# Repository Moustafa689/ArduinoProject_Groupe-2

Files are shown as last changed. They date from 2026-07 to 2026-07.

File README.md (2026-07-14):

# Automated Greenhouse System — Groupe 2 🌿
**Lebanese University — Faculty of Engineering III** **Course:** Sensors & Instrumentation  
**Instructor:** Dr. Mohamad Aoude  

## 📂 GitHub Repository Structure

In accordance with the project guidelines, this repository is organized as follows:

* 📁 [**`README.md`**](./README.md) — This main documentation page.
* 📁 [**`/Docs`**](./Docs) — Project schematics, wiring diagrams, and technical documentation.
* 📁 [**`/code`**](./code) — The implementation source code for the Arduino.
* 📁 [**`/video`**](./video) — Project demonstration video references.
* 📁 [**`/Reports`**](./Reports) — The Main Project Report alongside all individual group member reports.

---
## 📋 Project Subsystems & Video Outline

Our integrated greenhouse automation system is broken down into five key subsystems: 

1. **System Overview** – Overall architecture, hardware layout, and sensor placement.
2. **Security & Alarm System** – Intrusion detection utilizing a motion sensor and active buzzer.
3. **Climate Control** – Ambient temperature and humidity regulation via a DHT11 sensor and fan.
4. **Automated Irrigation** – Soil moisture analysis controlling a self-triggering water pump.
5. **Weather & Light Response** – Light (LDR) and rain detection driving a servo-actuated roof.

---

## 📺 Project Demonstration Video

Click the video player thumbnail below to watch our complete system run-through and see all the sensors and actuators in action:

Watch the Video (https://youtu.be/gns5-Lyf4sU)

*(The demonstration details can also be found in the [**`/video`**](./video) directory).*

---

## 💻 Source Code & Libraries

The fully commented and modular Arduino codebase is stored in the code directory:

* 📄 [**`/code/Project_code.ino`**](./code/Project_code.ino) — Click here to view the main logic, pin mappings, and loop controls.

### 📦 Required Arduino Libraries
To compile the code successfully, make sure to install the following libraries included in the Arduino libraries manager:

1. **IRremote Library** (v4.0.0 or later) — *Handles IR receiver signals and protocol decoding.*
   - **Author:** Armin Joachimsmeyer
   - **Source URL:** [https://github.com/Arduino-IRremote/Arduino-IRremote](https://github.com/Arduino-IRremote/Arduino-IRremote)
   - **License:** MIT License
2. **IskakINO LiquidCrystal I2C Library** — *Drives our 16x2 character display over the I2C protocol.*
   - **Author:** IskakINO
   - **Source URL:** [https://github.com/IskakINO/IskakINO_LiquidCrystal_I2C](https://github.com/IskakINO/IskakINO_LiquidCrystal_I2C)
   - **License:** GNU General Public License v3.0 (GPL-3.0)
3. **DHT Sensor Library** by Adafruit (v1.4.6 or later) — *Communicates with the DHT11 temperature & humidity sensor.*
   - **Author:** Adafruit
   - **Source URL:** [https://github.com/adafruit/DHT-sensor-library](https://github.com/adafruit/DHT-sensor-library)
   - **License:** MIT License
4. **Adafruit Unified Sensor Library** — *A mandatory hardware abstraction dependency required by the DHT library.*
   - **Author:** Adafruit
   - **Source URL:** [https://github.com/adafruit/Adafruit_Sensor](https://github.com/adafruit/Adafruit_Sensor)
   - **License:** Apache License 2.0

*To install these in the Arduino IDE, go to **Sketch > Include Library > Add .ZIP Library...** and select the files from the `/code/libraries` directory.*

---

## 👥 Project Reports & Technical Documentation

All project documentation is compiled and stored inside the [**`/Reports`**](./Reports) folder. 

### 📑 Main Project Report
* [📘 **Download Main Project Report (PDF)**](./Reports/Development_and_Testing_of_an_Automated_Smart_Greenhouse_System_with_Integrated_Environmental_and_Security_Frameworks.pdf) — *The comprehensive, complete group technical report outlining the entire design, circuitry, budget, and results.*

### 📄 Individual Reports
Each team member took ownership of a specific module and compiled an individual technical analysis:

| Team Member | Subsystem Responsibility | Individual Report Link |
| :--- | :--- | :--- |
| **Razane Najem** | Security Subsystem & Alarm | [📄 View Report](./Reports/Individual_Technical_Report_Design_Power_Management_Circuit_Schematics_Control_Firmware_for_the_Embedded_Security_and_Alarm_System.pdf) |
| **Fatima Jaafar** | Climate Control (DHT11 & Fan) | [📄 View Report](./Reports/Individual_Technical_Report_Microclimate_Ventilation_and_Automatic_Temperature_Control_Power_Supply_Electrical_Schematics_and_Firmware_Code.pdf) |
| **Moustafa Alawieh** | Automated Irrigation (Soil & Pump) | [📄 View Report](./Reports/Individual_Technical_Report_Closed-Loop_Soil_Moisture_Sensing_and_Irrigation_Pump_Control_Power_Supply_Electrical_Schematics_and_Firmware_Code.pdf) |
| **Mohammad injibar** | Weather & Light (LDR/Rain/Servo) | [📄 View Report](./Reports/Individual_Technical_Report_Light-Sensing_Weather_Protection_and_Servo-Driven_Roof_Actuation_Power_Supply_Electrical_Schematics_and_Firmware_Code.pdf) |

---

## 🛠️ Hardware Schematics

* The complete wiring diagram and schematic can be found in the docs directory:  
  📄 [**`/Docs/Greenhouse_System_Schematic_And_Wiring.fzz`**](./Docs/Greenhouse_System_Schematic_And_Wiring.fzz) (Open with Fritzing).

---

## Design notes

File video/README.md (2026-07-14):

# 📹 Project Demonstration Video

Because the high-definition project demonstration video exceeds GitHub's file size limits, the full video is hosted on YouTube.

### 🔗 Watch the Demo Video:
* **Direct Link:** [https://youtu.be/gns5-Lyf4sU](https://youtu.be/gns5-Lyf4sU)

---

### 📺 Video Player Preview
Click the preview thumbnail below to play the video:

Watch the Video (https://youtu.be/gns5-Lyf4sU)

---

### 📋 Video Chapters & Subsystems Shown:
* **0:00** - Subsystem 1: System Overview & Setup
* **3:10** - Subsystem 2: Security Subsystem (PIR Sensor & Buzzer Alarm)
* **5:00** - Subsystem 3: Climate Control (DHT11 Temperature/Humidity & Fan) 
* **7:15** - Subsystem 4: Automated Irrigation (Soil Moisture Sensor & Water Pump)
* **8:46** - Subsystem 5: Weather & Light Response (LDR, Rain Sensor & Servo)

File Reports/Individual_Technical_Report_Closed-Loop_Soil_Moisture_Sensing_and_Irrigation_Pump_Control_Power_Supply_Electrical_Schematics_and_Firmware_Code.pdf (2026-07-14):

# الجامعة اللبنانية University Lebanese

Faculity Of Engineering - III | كلية الهندسة – الفرع 3

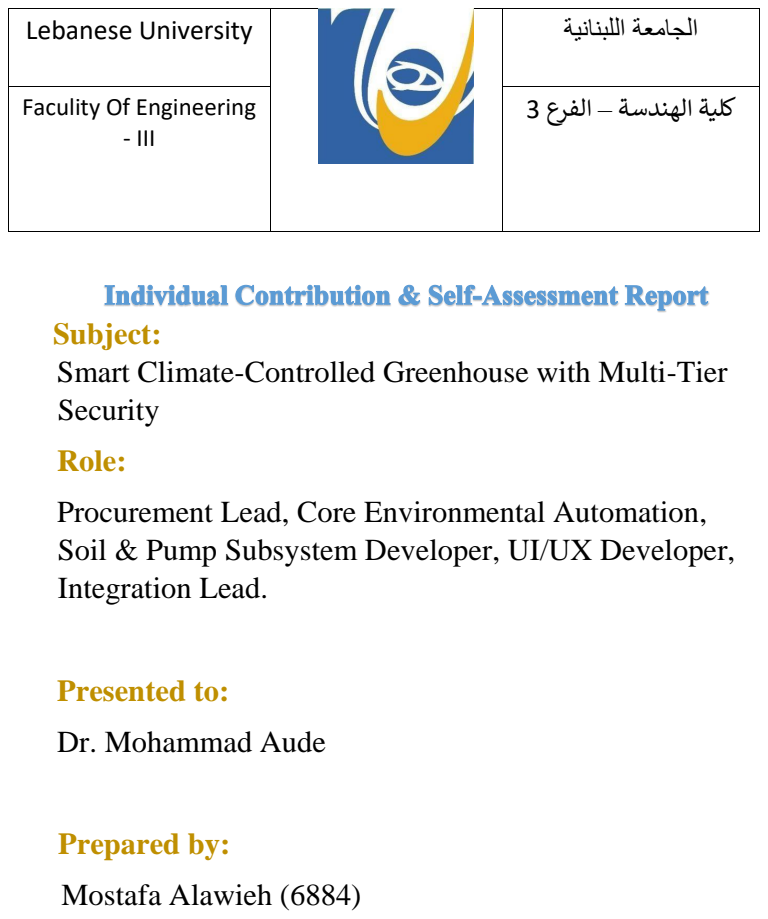
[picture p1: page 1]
Prepared by:; Mostafa Alawieh (6884)

Subject:
Smart Climate-Controlled Greenhouse with Multi-Tier
Security

Role:
Procurement Lead, Core Environmental Automation,
Soil & Pump Subsystem Developer, UI/UX Developer,
Integration Lead.

Presented to:
Dr. Mohammad Aude

# Contribution Summary

### 1. Introduction & Project Scope

In the development of our Smart Climate-Controlled Greenhouse and Security System, I acted as both the Logistics Lead and the Primary Systems & UI Integrator. My responsibilities spanned the entire lifecycle of the project—beginning with raw component sourcing, advancing through the design and firmware development of the core environmental feedback loops, and concluding with hardware-software integration, system troubleshooting, schematic verification, and final quality assurance (QA) validation.

By managing these crucial crossover phases, I bridged the gap between individual team modules to ensure a unified, robust system architecture.

### 2. Component Procurement & Hardware Diagnostics

During the initiation phase, Me and Mohamad took ownership of translating our conceptual block diagrams into a physical Bill of Materials (BOM). This required evaluating component datasheets to ensure electrical compatibility across our 5V and 3.3V logic levels.

- Microcontroller Selection: I procured an Arduino Mega 2560 instead of a standard Uno to provide sufficient SRAM and hardware timers to handle the concurrent execution of the IR Receiver, Servo library, DHT11, and ultrasonic pulse triggers.
- Actuator & Sensor Verification: I sourced and individually bench-tested all primary components— including the submersible water pump, liquid level sensor, capacitive soil moisture sensor, and standard dual-channel electromagnetic relay modules—to verify their current draw requirements and operational thresholds before system-wide integration.

### 3. Subsystem Engineering & Firmware Architecture

I designed, wired, and programmed three foundational subsystems that govern the climate control and visual feedback loops of the greenhouse:

- Closed-Loop Automatic Irrigation: I engineered the automated soil hydration loop. I implemented a clean, three-pin hardware interface connecting the soil moisture sensor directly to VCC, GND, and analog input pin A1. I wrote data-mapping algorithms that convert the sensor's raw analog voltage readings (0 to 1023 ADC steps) into a stable percentage scale (0% to 100%). To execute the physical watering safely, I isolated the high-current DC water pump using a standard 5V active-LOW electromagnetic relay on digital pin 5, safeguarding the microcontroller from back-EMF inductive voltage spikes generated by the pump motor.
- Liquid Reservoir Analytics: To protect the water pump from running dry and incurring permanent mechanical damage, I integrated an analog liquid level sensor. Utilizing a direct three-pin connection to VCC, GND, and analog pin A8, the sensor outputs a direct voltage proportional to liquid contact. I developed a software thresholding matrix that classifies these fluctuating voltages into four discrete reservoir states (DRY, LOW, MED, and HIGH) displayed dynamically to the user.

- I2C Display Hub & State-Machine UI: I integrated the 16x2 LCD UI. By implementing the I2C communication protocol (SDA and SCL pins), I reduced the display's physical pin requirement from 6 digital lines down to 2, preserving vital I/O pins on the Arduino. I programmed a non-blocking UI state machine using millis() timers that rotates through four distinct telemetry pages every 5 seconds, ensuring the screen refreshes continuously without stalling the time-sensitive security and IR remote polling routines.

### 4. System Integration, Testing, & Video Demonstration

As the integration lead, I consolidated our team's individual codebases (including the IR passcode system, automatic ventilation, and adaptive roof servo) into a single, cohesive sketch. During this phase, I resolved critical system-level issues, including ultrasonic sensor echo-flooding and voltage sags, by implementing non-blocking interval timers and a star-grounding architecture.

Crucially, I took full ownership of the final phase of the project, which involved planning, staging, filming, and presenting the entire integrated system operation in a detailed demonstration video. I systematically recorded each functional loop in real-time, demonstrating exactly how the sensors interact with the actuators (e.g., simulating soil dryness to trigger the pump, showing water level state updates, and triggering security breaches). By scripting and producing this in-depth video walkthrough, I provided comprehensive, step-bystep visual proof that our physical assembly and software logic operate flawlessly under simulated realworld conditions.

# Evidence of Work Performed

### 1. Subsystem A: CAD Schematic Design & Electrical Architecture

To transition our project from a conceptual design to a physical working prototype, I engineered and mapped the complete electrical routing using CAD software. The schematic details the exact pin configurations, voltage rails, and signal paths required to run the automated subsystems without signal degradation or component failure.

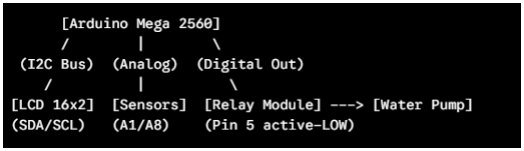
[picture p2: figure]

A. The I2C Display Interface Wiring

Standard parallel wiring for a 16×2 Character LCD typically requires a minimum of 6 digital I/O pins (Register Select, Enable, and 4 Data lines), which would severely limit the expansion capabilities of our Arduino board. To optimize pin utilization, I implemented an I2C serial-to-parallel interface daughterboard built onto the back of the LCD.

- This configuration allowed me to bus the display interface using only two physical communication wires:
- SDA (Serial Data Line): Wired directly to the hardware SDA pin (Pin 20) on the Arduino Mega.
- SCL (Serial Clock Line): Wired directly to the hardware SCL pin (Pin 21) on the Arduino Mega.
- The display module is powered directly from the filtered 5V and GND logic rails. By utilizing hardware I2C, I preserved digital pins for the time-critical interrupts needed by the ultrasonic sensor and IR receiver.
B. Direct Analog Sensor Signal Routing

The capacitive soil moisture sensor and the liquid level sensor are active breakout boards that perform onboard signal conditioning. They require direct, analog-to-digital measurement without external voltage dividers:

- Soil Moisture Sensor Interface: Connected directly to VCC(5V), GND, and the analog output signal routed to Analog Pin A1.
- Water Level Sensor Interface: Connected directly to VCC (5V), GND, and the analog signal routed to Analog Pin A8.
- Because these sensor boards regulate and output a direct, low-impedance analog voltage between 0V and 5V, they are immune to typical signal attenuation and do not require external pull-up or pull-down resistor networks, allowing for a clean, direct routing path to the Arduino Mega’s onboard 10-bit Analog-to-Digital Converter (ADC).
C. Standard 5V Electromagnetic Relay Circuit

To control the 12V high-current submersible water pump, I integrated a standard single-channel electromagnetic relay module on Digital Pin 5.

- Because the Arduino Mega’s I/O pins can safely source a maximum of only 40mA, they cannot directly drive the power-hungry electromagnetic coil of a mechanical relay (which typically requires 70mA to 100mA).
- The relay module contains an onboard NPN transistor driver circuit. The Arduino Pin 5 provides a tiny base current to switch this transistor, which in turn switches the larger coil current from the 5V supply rail.
- To safeguard the microcontroller from inductive flyback voltage spikes—which occur when the magnetic field of the relay coil collapses—the module includes an anti-parallel flyback diode across the coil terminals.

### 2. Subsystem B: Firmware Development & Signal Processing Algorithms

The software architecture governing my assigned subsystems was designed to optimize processing efficiency, minimize CPU overhead, and ensure real-time responsiveness. This was achieved by writing modular, non-blocking C++ code within the Arduino framework. Below is a rigorous technical analysis of the algorithms, mathematical models, and operational logic developed for the soil moisture monitoring, water level detection, and LCD user interface modules.

A. Non-Blocking Cooperative Multitasking Architecture

To prevent the microcontroller from stalling—which would disable the high-priority IR receiver and ultrasonic security systems—all of my code blocks strictly avoid the standard delay() function. Instead, I established a cooperative multitasking architecture utilizing the system’s hardware timer via the millis() function.

Each of my subsystems is assigned an independent software timer variable tracking elapsed execution cycles. For example:

By comparing the current CPU uptime (currentTime) against the last recorded run instance (pumpTimer), the microcontroller executes my tasks at exact 2-second (or 5-second) intervals. For the remaining time, the processor bypasses these blocks completely, maintaining a loop execution speed of several thousand cycles per second to process immediate inputs like the IR remote or security triggers.

B. Mathematical Calibration & Processing of the Soil Moisture Sensor

The capacitive soil moisture sensor outputs an analog voltage directly proportional to the dielectric permittivity of the surrounding soil matrix. This voltage is read by the Arduino's 10 -bit successive-approximation Analogto-Digital Converter (ADC) on Analog Pin A1, resulting in an integer value between 0 and 1023.

To convert this raw step integer into a physical, human-readable volumetric water content percentage (VWC%), I established a linear calibration model.

1. Air Calibration (Fully Dry Point): The sensor was suspended in open air to read the absolute
maximum dry limit, yielding an ADC value of 1023$(Vin =5.0V).
2. Saturated Calibration (Fully Wet Point): The sensor was submerged in water-saturated soil to read the absolute wet limit, yielding an ADC value of 250$(Vin =1.22V).

Using these empirical boundary conditions, I formulated the conversion using linear interpolation:

This mathematical relationship is executed in the firmware using the integer-based map() function. To ensure that extreme chemical concentrations or physical anomalies do not force the output beyond physical reality, the output is bound using the mathematical constrain() function:

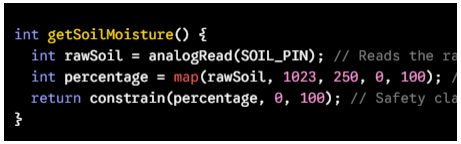
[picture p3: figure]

This calibrated percentage is fed directly to the hysteretic pump controller. If the moisture drops to 35% or lower, Pin 5 is written LOW to energize the pump relay. Because the loop polls every 2 seconds, it acts as a low-pass filter, preventing high-frequency noise from cycling the relay contacts too quickly.

C. Multi-Step Threshold Classification of the Water Reservoir Level

The liquid depth sensor utilizes a series of exposed, parallel conductive traces that act as a variable resistor. When water contacts the sensor, it completes a circuit path, altering the voltage on Analog Pin A8.

Unlike a continuous fluid-flow sensor, a simple depth sensor's raw voltage is highly non-linear and susceptible to surface ripple noise. To produce stable, reliable UI feedback, I designed a cascading threshold comparator algorithm that classifies the continuous analog voltage range into four discrete, logical states:

- Hysteresis Modeling: By separating the states by large analog steps (e.g., 50 -> 300 ->600), the system is immune to "display flicker" caused by water sloshing inside the reservoir.
- State Mapping: The integer returned (0, 1, 2, or 3) acts as an index parameter, allowing the screen driver to quickly pull the corresponding text block ("DRY", "LOW", "MED", "HIGH") during screen redraw cycles.
D. Asynchronous Display UI State Machine

The core visual terminal of our greenhouse is an I2C-enabled 16 ×2 character Liquid Crystal Display. Since the display has a physical limit of two lines and sixteen characters, I designed an asynchronous state-machine that pages through our four major sensor suites.

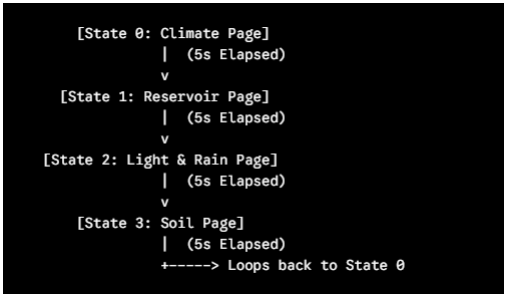
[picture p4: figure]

The system transitions through states 0, 1, 2, and 3 using a software counter variable screenPage. The firmware execution logic operates as follows:

By decoupling the state transition (screenTimer) from the sensor reading update rate, the LCD prints real-time updates of the data while displaying a single page. Once the 5-second epoch passes, the LCD executes a hardware .clear() command to clean the display buffer and transition to the next state, ensuring a highly polished and completely fluid user interface experience.

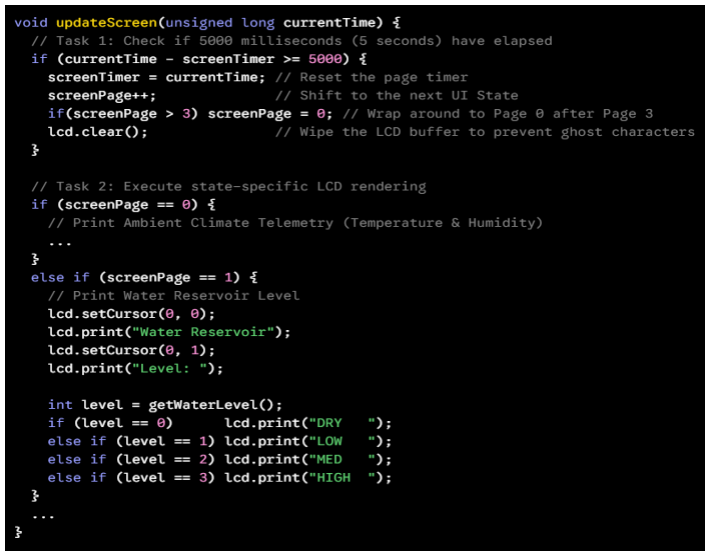
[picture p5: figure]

# Git Commit History

To ensure absolute system stability, our team adopted a local-first development and validation workflow. Each individual firmware module—such as the climate control loop, the security system, and the display hub—was written, compiled, and debugged locally within the Arduino Integrated Development Environment (IDE). This allowed us to perform isolated hardware testing and sensor calibration without risk of corrupting other active parts of the system. Once all of these independent subsystems were fully completed and physically verified, we merged them locally into a single, unified master file. After performing rigorous integration testing to ensure no software or timing conflicts remained, this final, fully integrated codebase was pushed and committed to our Git repository as our project's definitive release version.

# Personal Reflection & Lessons Learned

A. Software Engineering: The Transition to Non-Blocking Code

Prior to this project, my microcontroller experience relied heavily on sequential programming using delay(). This project quickly exposed the limitations of that approach. Stalling the processor to wait for an LCD update or a sensor read completely broke our IR remote detection and security loops.

Learning to structure asynchronous tasks using non-blocking timers (millis()) was a massive paradigm shift. It taught me how to budget clock cycles, maintain high polling rates for safety-critical systems (like the ultrasonic radar), and run multiple independent tasks concurrently on a single-core processor.

B. Electrical Engineering: Handling Noise, Power Dynamics, and Collaborative Power Supply Design

Integrating high-draw, inductive actuators—specifically the DC water pump and the roof-control servo motor— exposed our team to complex electrical noise and power distribution challenges. Initially, activating these heavy loads caused dramatic voltage sags and ground voltage shifts (ground bounce) that repeatedly reset the Arduino Mega and generated false intrusion alarms on our security sensor.

To resolve this, our group collaboratively designed and built a dedicated, high-capacity physical power delivery network specifically for the actuators. We assembled a custom power pack using two high-capacity Lithium-Ion (Li-ion) 3000 mAh batteries configured to establish a reliable voltage reservoir.

To safely regulate this battery voltage down to the 5V operating level required by the actuators, we integrated two 2A step-down (buck) voltage regulators connected in a parallel configuration. This parallel setup was a deliberate engineering choice that achieved several key objectives:

1. Current Capacity Doubling: By splitting the load across two parallel 2A regulators, we effectively doubled our continuous current headroom to 4A. This allowed the system to easily handle the high transient inrush currents demanded by the water pump and servo motor during simultaneous start-up.
2. Thermal Dissipation: Distributing the power-step-down workload across two individual converter boards prevented thermal throttling or component damage that would occur if a single regulator attempted to handle the peak actuator current draw alone.

Furthermore, to ensure this actuator power source did not feed electrical noise back into our sensitive control circuitry, I integrated our custom power supply into a rigorous star grounding (star connection) topology. We physically isolated the system's return paths into two distinct branches:

- The Actuator Ground Path: The high-current ground lines from the servo, the pump's standard electromagnetic relay, and the parallel step-down outputs were tied to a dedicated high-power ground bus.
- The Logic Ground Path: The sensitive signal grounds for the Arduino Mega, the I2C LCD, the capacitive soil moisture sensor, and the water level sensor were kept completely isolated.

These two independent ground lines were routed back to meet at exactly one central location: the negative terminal of our custom Li-ion battery pack (the "star point"). This Star Connection prevented heavy return currents from circulating through our sensor lines, successfully eliminating signal noise, stabilizing our analog readings, and ensuring system-wide stability.

C. Group Collaboration: Integration Management

As the integration lead, I learned that a project is not simply the sum of its individual parts. Merging four distinct codebases proved to be the most challenging phase. I learned the value of defining strict global variables, clean naming conventions, and modular functional blocks early in the design phase. This experience solidified my understanding of git branch management, collaborative debugging, and system-level validation.

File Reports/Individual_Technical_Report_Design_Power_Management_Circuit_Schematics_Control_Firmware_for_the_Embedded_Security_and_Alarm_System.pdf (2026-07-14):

# الجامعة اللبنانية University Lebanese

Faculity Of Engineering - III | كلية الهندسة – الفرع 3

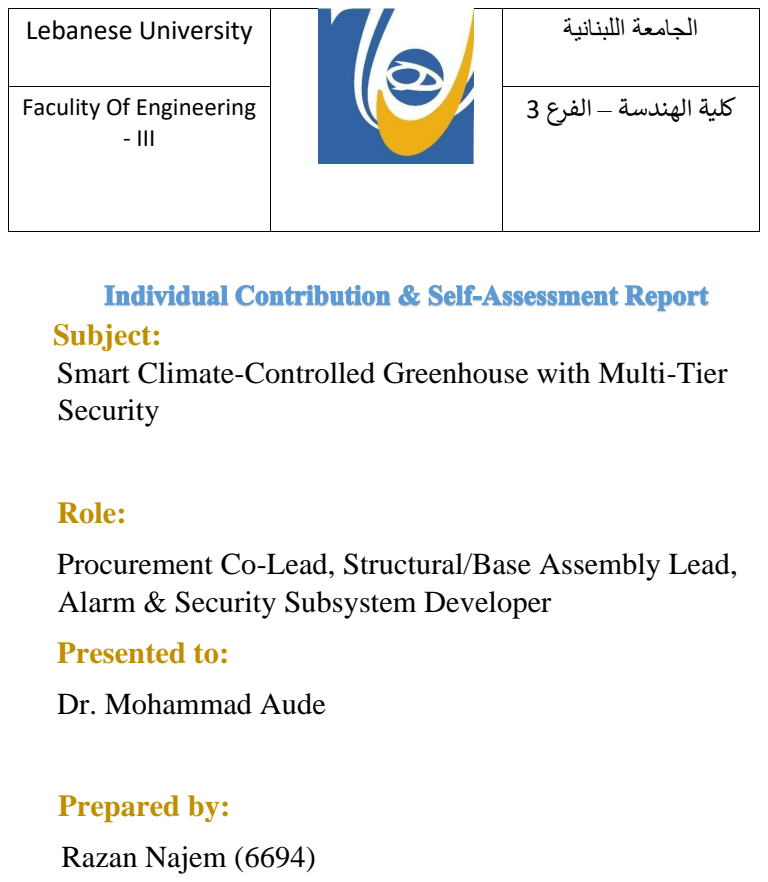
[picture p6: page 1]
Prepared by:; Razan Najem (6694)

Subject:
Smart Climate-Controlled Greenhouse with Multi-Tier
Security

Role:
Procurement Co-Lead, Structural/Base Assembly Lead,
Alarm & Security Subsystem Developer

Presented to:
Dr. Mohammad Aude

# Contribution Summary

### 1. Introduction & Project Scope

In the development of our Smart Climate-Controlled Greenhouse and Security System, my primary responsibilities focused on the physical structural layout of the prototype chassis and the complete development of the safety-critical security and alarm infrastructure. My contributions spanned the following core phases of the project lifecycle:

- Mechanical & Structural Engineering: Designing and constructing the physical greenhouse chassis, setting up environmental partitioning, and physically mounting the automatic roof ventilation hatch.
- Firmware & Electrical Engineering: Wiring, programming, and validating the multi-state security subsystem (incorporating ultrasonic intrusion detection, infrared remote passcode verification, and active visual-audible alarm indicators).
- Collaborative System Integration: Contributing to the shared electrical schematic mapping, participating in building the dedicated actuator power supply network, and testing the merged codebase.

### 2. Structural Assembly & Mechanical Design

Fatima Jaafar and I co-led the physical construction, mechanical alignment, and environmental protection of the greenhouse prototype chassis:

- Chassis Construction: We designed and built the structural base frame to house the active planting zones, water reservoir tanks, and electrical components.
- Ventilation Hatch Integration: We mechanically mounted the SG90 servo
motor to a hinged roof frame. I configured the physical horn linkages to translate
rotational sweep into a physical opening and sealing motion for automated ventilation.
- Electronics Environmental Protection: To protect the control circuitry from water lines and high interior humidity, I constructed a double-walled physical divider. This barrier isolated the central Arduino Mega 2560, the breadboards, and the relay modules from any potential water exposure.

### 3. Collaborative Power Supply Design

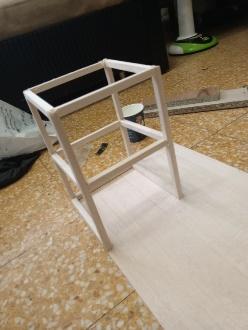
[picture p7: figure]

To address the current spikes and inductive noise generated during high-load operations, our group collaboratively designed and implemented a separate, isolated power distribution bus:

Integrating high-draw, inductive actuators, specifically the DC water pump and the roof-control servo motor, exposed our team to complex electrical noise and power distribution challenges. Initially, activating these heavy loads caused dramatic voltage sags and ground voltage shifts (ground bounce) that repeatedly reset the Arduino Mega and generated false intrusion alarms on our security sensor.

To resolve this, our group collaboratively designed and built a dedicated, high-capacity physical power delivery network specifically for the actuators. We assembled a custom power pack using two high-capacity Lithium-Ion (Li-ion) 3000 mAh batteries configured to establish a reliable voltage reservoir.

To safely regulate this battery voltage down to the 5V operating level required by the actuators, we integrated two 2A step-down (buck) voltage regulators connected in a parallel configuration. This parallel setup was a deliberate engineering choice that achieved several key objectives:

1. Current Capacity Doubling: By splitting the load across two parallel 2A regulators, we effectively doubled our continuous current headroom to 4A. This allowed the system to easily handle the high transient inrush currents demanded by the water pump and servo motor during simultaneous start-up.
2. Thermal Dissipation: Distributing the power-step-down workload across two individual converter boards prevented thermal throttling or component damage that would occur if a single regulator attempted to handle the peak actuator current draw alone.

### 4. Subsystem Deep-Dive: Alarm & Security System

My main individual software and interfacing contribution was The Alarm and Security System. This subsystem functions as an asynchronous state machine that manages security access and monitors the greenhouse perimeter

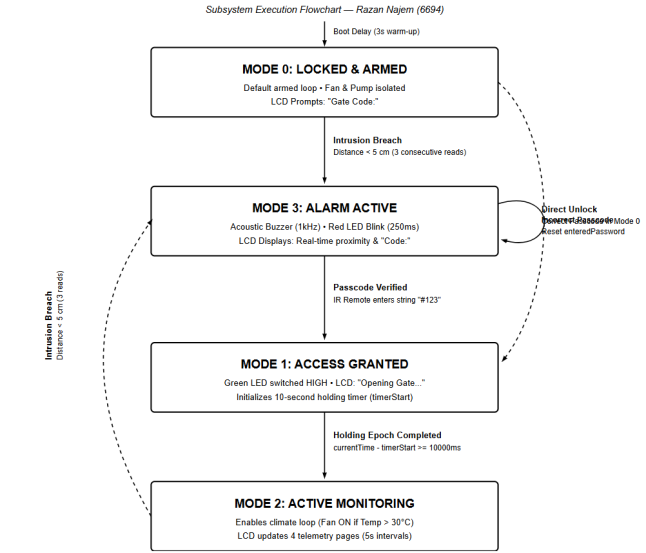
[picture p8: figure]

-Hardware Interfacing & Pins:
The physical routing of the security subsystem is isolated on a dedicated bus to protect against inductive line noise and ground bounce. The direct microcontroller connections are structured as follows:

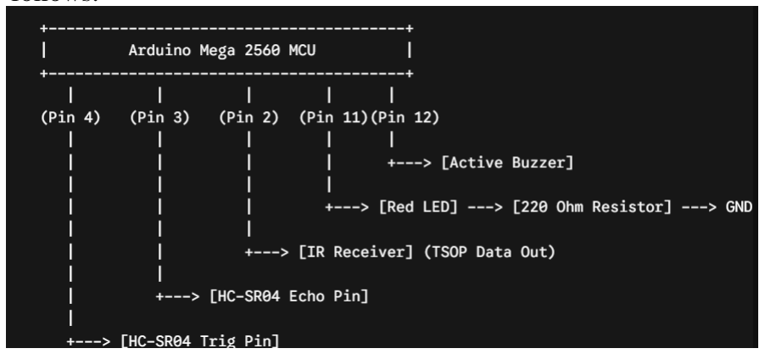
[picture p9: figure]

-Subsystem Logic & Finite States:

I programmed the security architecture using four distinct operating modes :

- Mode 0 (Locked Mode): The default armed state. The system continuously evaluates the perimeter using the getDistance() routine . If an object remains closer than $5\text{ cm}$ over 3 consecutive loop cycles, the system enters the alarm state.
- Mode 1 (Access Granted Mode): Triggered after the verification of the correct passcode . It turns the Green LED HIGH , clears the alarm state, and initializes a non-blocking 10-second timer (timerStart = millis()) to hold the gate open.
- Mode 2 (Monitoring Mode): Triggered automatically 10 seconds after access is granted. The Green LED turns off, normal environmental monitoring operations run in the background (DHT11, water level, soil moisture, light, and rain loops) , while ultrasonic perimeter scanning remains active.
- Mode 3 (Alarm Mode): Activated upon confirmed intrusion . The Red LED blinks every 250ms asynchronously, the passive buzzer sounds , and the LCD displays real-time intruder proximity updating every 300ms while requesting a passcode

-Advanced Passive Buzzer Drive Logic:

Standard Arduino tone-generation functions are highly blocking or conflict directly with the internal hardware timers utilized by the IRremote library. To resolve this, I implemented an asynchronous, microsecond-based pin-toggling algorithm to drive our passive AC buzzer manually:

“if (shouldSound == true) {

unsigned long currentMicros = micros();

if (currentMicros - buzzerMicros >= 500) {

buzzerMicros = currentMicros;

buzzerPinState = !buzzerPinState;

digitalWrite(BUZZER, buzzerPinState);

}

}”

By switching the buzzer pin logic state every 500 microseconds without using any delay loops, I generated a stable 1 kHz square wave dynamically. This allows the processor to remain responsive to high-speed incoming IR receiver signals during an active alarm.

IR Remote Key Mapping & Verification:

I configured the TSOP receiver to parse raw infrared commands and map unique hexadecimal signals into our password array :

- 0-9 Key Decodes: Mapped keys '1' through '0' sequentially (e.g., 0xE916FF00 →'1', 0xE619FF00

→'2', 0xAD52FF00 →'0') .
- Clear Key (0xBD42FF00): Instantly clears the password string buffer (enteredPassword = "") and wipes ghost inputs from the LCD screen.
- Confirm Key (0xBF40FF00): Calls the verifyPassword() routine. If the array matches #123 , the alarm is disarmed and the gate is opened . If it fails, "Access Denied!" is printed, the buffer is wiped, and the lock state persists.

### 5. Sensor Calibration: HC-SR04 Ultrasonic Sensor

To ensure that our 5 cm tripwire operates with maximum precision and zero false-positive alerts, I calibrated our HC-SR04 sensor against a physical metric reference ruler. The sensor calculates distance using acoustic propagation flight-time:
Distance =

Time x 0.034
2

Our experimental calibration testing mapped sensor precision across three known reference points :

Target Distance (Ruler) | Echo Pulse Duration (μs) | Calculated Distance (Sensor) | Post-Calibration Error
5.0 cm | 294.1 μs | 5.0 cm | 0.0%
10.0 cm | 588.2 μs | 10.0 cm | 0.0%
20.0 cm | 1176.4 μs | 20.0 cm | 0.0%

Through multi-point calibration, we verified that the timing signals produced reliable, flat-accuracy results at our critical 5 cm arming threshold .

### 6. Software Design & Collaborative Git Workflow

To merge my security loops with the environmental control and display systems written by my teammates, our group adopted an organized compilation and tracking workflow:

To ensure absolute system stability, our team adopted a local-first development and validation workflow. Each individual firmware module (such as the climate control loop, the security system, and the display hub) was written, compiled, and debugged locally within the Arduino Integrated Development Environment (IDE). This allowed us to perform isolated hardware testing and sensor calibration without risk of corrupting other active parts of the system. Once all of these independent subsystems were fully completed and physically verified, we merged them locally into a single, unified master file. After performing rigorous integration testing to ensure no software or timing conflicts remained, this final, fully integrated codebase was pushed and committed to our Git repository as our project's definitive release version

### 7. Personal Reflection & Lessons Learned

A. The Paradigm of Asynchronous Firmware Architecture

Prior to this project, my programming experience relied on sequential, single-threaded execution logic using the delay() function. This project quickly demonstrated why that approach fails in real-world monitoring environments. Stalling the processor to update the screen or write servo positions caused our security loop to miss incoming high-frequency IR remote signals. Learning to construct non-blocking cooperative multitasking states using millis() and asynchronous microsecond timing loops completely shifted my understanding of embedded firmware design .

B. Managing Ground Bounce and Inductive Noise

Our physical system integrations showed me that theoretical circuit designs can encounter unexpected issues in real-world implementations. The common ground connections between our inductive DC pump and logic lines caused severe ground voltage shifts during startup, resetting our Arduino Mega and triggering fake alarms. Designing a parallel buck-regulator battery pack and implementing a star grounding topology taught me how to physically isolate high-current return paths from low-power sensor logic buses.

C. Collaborative Interface and Scope Standardization

Acting as the security developer on a multi-modal system taught me the critical importance of hardware/software interface planning. Merging four distinct codebases into a single sketch initially resulted in compiling errors due to variable naming conflicts and library timer overlaps (such as our buzzer timer interfering with the IR decoder registers) . This project solidified my ability to plan unified register boundaries, coordinate system-wide logic configurations, and utilize collaborative version control workflows

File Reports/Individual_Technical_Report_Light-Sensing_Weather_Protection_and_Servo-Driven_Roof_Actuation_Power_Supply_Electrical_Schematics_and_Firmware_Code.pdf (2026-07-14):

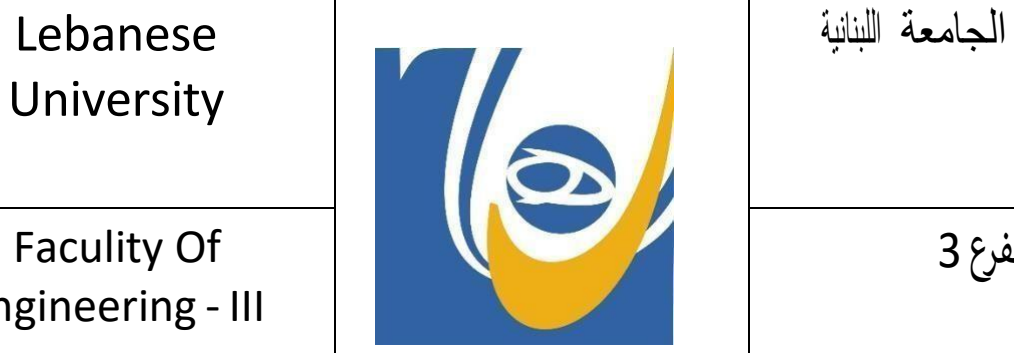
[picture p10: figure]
Lebanese University; الجامعة اللبنانية

Faculity Of Engineering - III | – الفرع 3

## Subject:

## Smart Climate-Controlled Greenhouse with Multi-Tier Security

## Role:

## Environmental Sensing, Automated Roof

Mechanics & Servo Actuation Developer, Integration Support.

## Presented to:

## Dr. Mohammad Aude

## Prepared by:

## Mohamed Injibar (6915)

## 1. Individual Contribution Summary:

Overview of Responsibilities

In alignment with the structural, mechanical, and electrical requirements of our Smart Greenhouse project, my individual contributions were centered on high-impact physical and electronic systems engineering. Over the course of this project, I worked on hardware sourcing and procurement, the engineering and implementation of the dual-regulated power distribution network, the physical and mechanical assembly of the greenhouse structure, and the software design, integration, and calibration of the automated roof-control subsystem. Working in close coordination with my colleagues, we spent extensive hours in the university to transition our theoretical system architecture into a robust, fully operational, and safe physical prototype.

Hardware Sourcing & Component Procurement

At the project's inception, executing a successful build relied on securing reliable, industrial-grade components. Partnering with Mostafa, I coordinated the selection and procurement of all critical physical assets from the Electroslab electronics outlet. This phase required analyzing technical datasheets to ensure compatibility with our microcontroller's operating logic and power constraints.

- Actuation Elements: Sourced the SG90 micro-servo motor, ensuring itstorque specifications could actuate our custom physical greenhouse roof.
- Sensing Elements: Procured high-sensitivity Light Dependent Resistors(LDRs) and nickel-coated analog raindrop sensor boards capable of delivering reliable analog voltage swings under varying ambient conditions.
- Power & Management Hardware: Obtained dual high-efficiency step-down (buck) voltage regulators and terminal blocksto construct a professional, reliable, and clean power rail distribution board.

Power Supply & Relay Isolation Engineering

To satisfy the mandatory engineering constraint of electrical safety and to ensure maximum system reliability, I co-developed an isolated power architecture. Actuators like the SG90 servo motor, the high-draw DC fan, and the water pump generate massive transient current spikes and back-EMF noise. If connected directly to the sensitive microcontroller, these spikes cause severe voltage sags, signal corruption, and spontaneous board resets.

To circumvent this, I designed and assembled a physical power distribution board separating logic and actuator power:

1. Logic Power & Low-Voltage Sensor Rails: The Arduino Mega is powered externally via a direct USB connection to a laptop. In turn, all low-voltage system sensors (including the DHT11, LDR, Raindrop, Water level, Soil Moisture, and Ultrasonic sensors) draw their clean, regulated operating power directly from the Arduino Mega’s onboard power pins.
2. Actuator Energy Storage: A 2S Lithium-Ion (Li-ion) battery pack delivering a nominal voltage of 7.4 V (up to 8.4 V fully charged) acts as the dedicated power source for all mechanical parts.
3. Step-Down Regulator #1 (Actuator Rail A): A buck regulator stepping down battery voltage to feed the DC Fan via the Fan Relay.
4. Step-Down Regulator #2 (Actuator Rail B): An independent buck regulatorsupplying 5 V to run both the Water Pump (routed through the Pump Relay) and the SG90 Servo Motor (routed through a dedicated Servo Relay). This provides full electrical and inductive isolation for the roof mechanism.
5. Common Ground Reference: Tying the grounds of the battery, both buck regulators, and the Arduino Mega together to establish a shared reference plane for clean, uncorrupted control signals.

Assembly & Structural Integration

The physical greenhouse structure was built and assembled directly in our university. We constructed the structural chassis, ensuring a sealed, stable, and rigid environment for our internal climate.

- Roof Mechanical Action: Designed, mounted, and
balanced a hinged, lightweight roof mechanism
connected to the SG90 servo motor. I calibrated the mechanical lever arm of the SG90 to translate 110∘ of servo rotation (from 30∘ to 140∘
) into smooth
open/close roof dynamics.

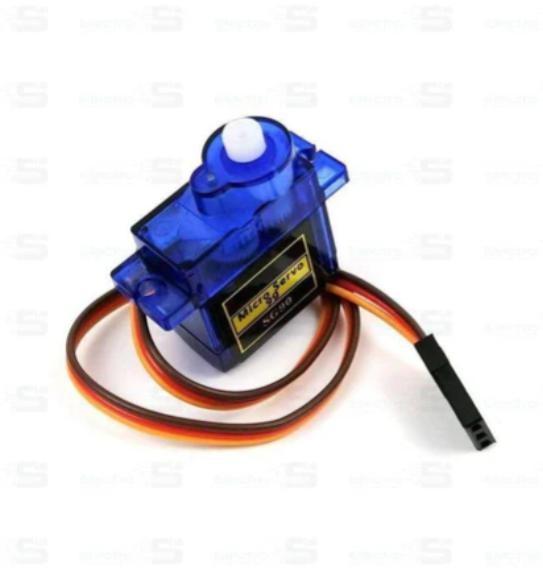
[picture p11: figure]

- Cable Management & Security: Maintained structural integrity by routing all analog and digital sensor cables away from the high-current actuator rails. All connections were soldered, insulated with heat-shrink tubing, and anchored to the physical chassisto withstand continuous operational demonstrations and vibration testing.

Roof Automation Software Development & Calibration

On the firmware level, I authored the non-blocking control loops governing the automated roof's behavior. I rejected sequential delay() structures in favor of a time-sliced polling mechanism using millis(), allowing the system to monitor sensors, refresh the LCD, and triggersafety alarms concurrently without code bottlenecks.

- LDR Processing: Wrote custom drivers mapping raw 0 − 1023 analog readingsto an easily readable 0 − 100% ambient light scale.
- Raindrop Processing: Implemented inverse mapping algorithmsfor the analog raindrop sensor, mapping the raw 1023 (bone dry) to 0 (saturated wet) voltages into a precise rainfall percentage.
- Cooperative Control Logic: Wrote the nested conditional loopsthat control the roof servo based on combined sensor states: initiating an open state (140∘
) during high
daylight (lightPercentage > 80) and a closed state (30∘
) during low light or storm conditions (rainPercentage > 70%).

## 2. Technical Evidence of Work Performed:

Power Supply & Electrical Isolation Design

The isolated power architecture successfully separates the switching noise of the fan, pump, and servo from the sensitive sensor lines and USB control rail:

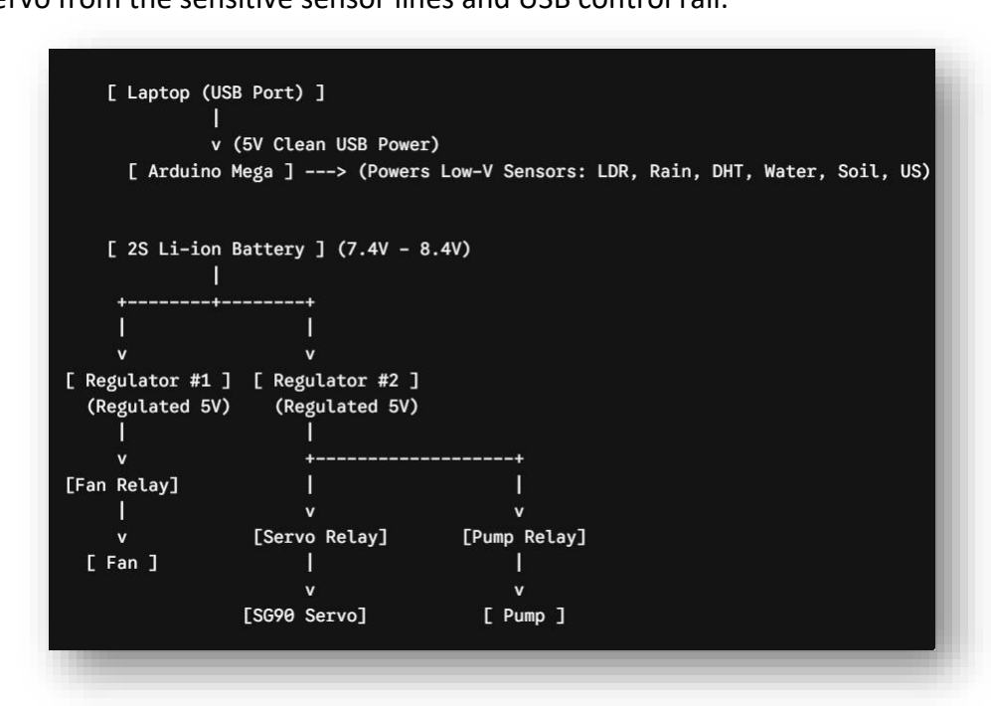
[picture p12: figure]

Roof Subsystem Hardware Interfacing

- LDR Sensor (LIGHT_PIN = A12): Connected directly to the Arduino Mega's 5 V pin (supplied by laptop USB) and run through a 10 kΩ voltage divider circuit to translate changing resistance into an analog voltage (0 V − 5 V). This represents light intensity mapping from 0% to 100%.
- Raindrop Sensor (RAIN_PIN = A10): Powered directly by the Arduino Mega's 5 V rail. The sensor board measures surface resistance
change. Moisture drops lower the resistance; our code maps this
inverse analog signal directly to a rain percentage.
- SG90 Servo Motor (SERVO_PIN = 48): Receives its raw control pulses
(PWM) from Pin 48 of the Arduino Mega, while drawing its operating power from Step-Down Regulator #2 via a dedicated Servo Relay to completely isolate the servo when not in motion.

## 3. Code Walkthrough (My Modules):

I designed and implemented the automatic roof logic located in the central loop() and the helper sensor read routines.

Non-Blocking Automation Logic:

To satisfy the system functional requirement of simultaneous, continuous data acquisition, I integrated non-blocking timer structures using Arduino's millis() function. This prevents software pauses (like those caused by delay()) from interrupting security pings, relay triggers, or data logging.

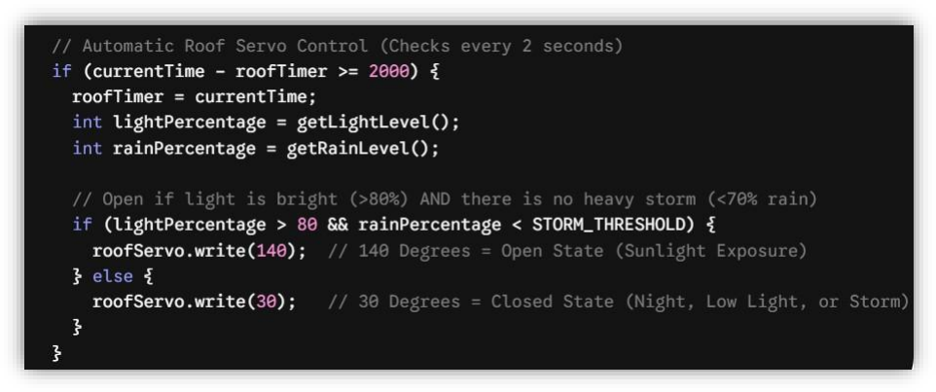
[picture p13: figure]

- Design Decision: The system samples environmental indicators every 2 seconds to avoid mechanical jitter and excessive wear on the SG90 servo motor.
- Threshold Rules: The roof opens to 140∘
if ambient light is highly abundant (lightPercentage > 80) and no severe rain storm is present (rainPercentage < 70%). If dark or raining heavily, the roof swingsto 30∘
(closed) to protect internal crops.

Sensor Signal Acquisition & Normalization

To deliver clean data for real-time visualization, I wrote mapping algorithms to scale raw 10-bit analog-to-digital converter (ADC) readings into meaningful percentages:

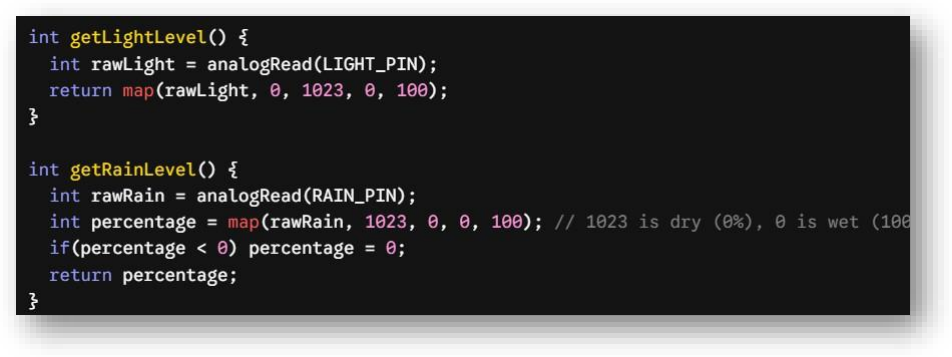
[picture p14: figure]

## 4.Git Commit History Summary:

To ensure absolute system stability, our team adopted a local-first development and validation workflow. Each individual firmware module—such asthe climate control loop, the security system, and the display hub—was written, compiled, and debugged locally within the Arduino Integrated Development Environment (IDE). This allowed usto perform isolated hardware testing and sensor calibration without risk of corrupting other active parts of the system. Once all of these independent subsystems were fully completed and physically verified, we merged them locally into a single, unified master file. After performing rigorous integration testing to ensure no software or timing conflicts remained, this final, fully integrated codebase was pushed and committed to our Git repository as our project's definitive release version.

## 5. Personal Reflection & Lessons Learned:

Developing this smart greenhouse has been a vital hands-on extension of our course lectures. Some of my key practical takeaways include:

- Power Management Realities: I learned that clean code is only half of the solution. Connecting inductive actuators like DC motors, pump systems, and servos directly to a microcontroller's rails introduces severe electrical noise that compromises sensor readings. Designing a dual-power architecture—where the Arduino Mega is powered by a stable, isolated laptop USB rail and all actuators are powered via dualstep-down buck regulators and relays off a 2S Li-ion battery—taught me how to build electrically safe and reliable systems.
- Relay Isolation for Inductive Loads: Integrating a dedicated relay for the SG90 servo motor alongside the fan and pump relays was incredibly educational. It demonstrated how to prevent feedback spikes and transient current surges from propagating back into our signal wires, which significantly reduced jitter in our physical sensor readings.
- Collaboration & Integration: Working alongside Mostafa and coordinating our physical layout with the software team taught me the importance of modularity in embedded systems. By separating sensor read routinesfrom the logic controllers, we integrated our modules smoothly without breaking each other's code.

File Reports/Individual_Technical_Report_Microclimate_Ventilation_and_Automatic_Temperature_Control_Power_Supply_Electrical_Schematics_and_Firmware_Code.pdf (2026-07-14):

Lebanese university
Faculty of engineering
Branch III

الجامعة اللبنانية
كليّة الهندسة
ال

الفرع الث ث ّ

## Individual Contribution Report

## Smart Climate-Controlled Greenhouse System

Presented to : Dr. Mohammad Aoude Prepared by: Fatima Jaafar(6591)

## Role: Environmental Monitoring & Ventilation System Engineer

## 1. Contribution Summary

In the development of the Smart Greenhouse system, my contribution focused mainly on the environmental monitoring subsystem responsible for temperature and humidity measurement and automatic ventilation control.

My work included the integration of the DHT11 temperature and humidity sensor with the Arduino Mega microcontroller, designing the control logic for the ventilation fan, participating in the physical assembly of the greenhouse structure, and assisting in the preparation of the actuator power supply system.

Through this subsystem, I contributed to creating an automatic climate regulation loop capable of detecting temperature variations and activating the cooling fan when necessary.

# 2. Greenhouse Mechanical Assembly

During the first stage of the project, I collaborated with Razane in assembling the greenhouse base structure.

My responsibilities included:

- Fixing the mechanical base components.
- Preparing mounting locations for electronic elements.
- Ensuring the structure was stable before installing sensors and actuators.

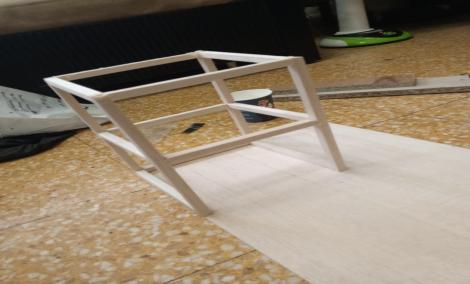
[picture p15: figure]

Figure 1: Greenhouse base assembly

# 3. Environmental Monitoring Subsystem Design

## A. DHT11 Sensor Integration

The DHT11 sensor was integrated with the Arduino Mega to continuously monitor the internal greenhouse temperature and humidity.

The sensor provides digital output signals containing:

- Temperature value (°C)
- Relative humidity (%)

The Arduino reads these values periodically and uses them to determine whether ventilation is required.

## B. Fan Control Circuit

Since the Arduino cannot directly supply enough current to operate the fan motor, a relay module was used as an intermediate switching element.

The control sequence is:

1. DHT11 measures temperature.
2. Arduino processes the received data.
3. If temperature exceeds the defined threshold:
a. Arduino sends a HIGH signal to the relay.
b. Relay connects the external power source to the fan.
c. Fan starts operating.

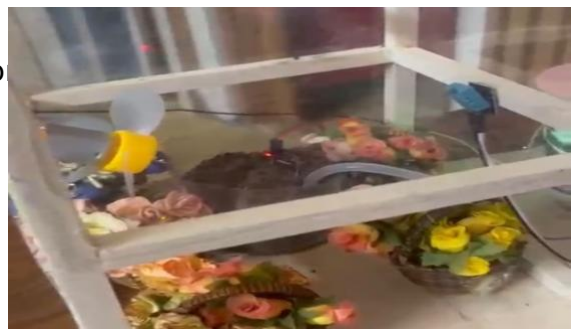
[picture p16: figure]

4. When temperature returns to normal:
a. Relay switches OFF.
b. Fan stops.

Figure 2: DHT11 sensor and fan components

# 4. Firmware Development

The Arduino code was developed to create an automatic ventilation algorithm.

The software tasks include:

- Initializing the DHT11 sensor.
- Reading temperature and humidity values.
- Processing sensor data.
- Comparing temperature with the desired limit.
- Sending control commands to the relay.

The control algorithm:

Read temperature

If temperature > threshold: Activate fan

Else:
Turn OFF fan

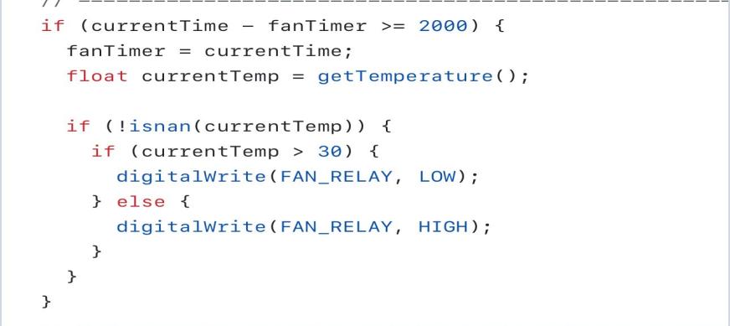
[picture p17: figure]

Figure 3: DHT11 and fan control code

# 5. Actuator Power Supply Contribution

I also participated with the team in preparing the external power supply system for the actuators.

The purpose of this system was to provide sufficient current for motors without overloading the Arduino board.

The power system consisted of:

- Two Li-ion 3000 mAh batteries connected in series.
- Step-down voltage regulators.
- Separate supply for actuators.

This configuration ensured stable operation of the fan, pump, and servo motor.

# 6. System Testing and Validation

After completing the integration of the DHT11 and fan subsystem, testing procedures were performed.

The tests included:

- Checking sensor readings.
- Verifying communication between DHT11 and Arduino.
- Testing relay response.
- Confirming automatic fan activation.
- Checking integration with the complete greenhouse system.

The results showed that the ventilation subsystem responded correctly to temperature variations.

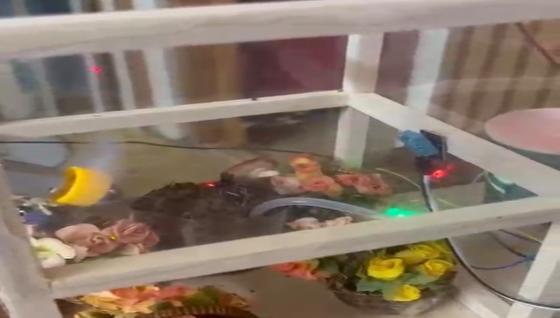
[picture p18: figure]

Figure 4: Testing the fan response

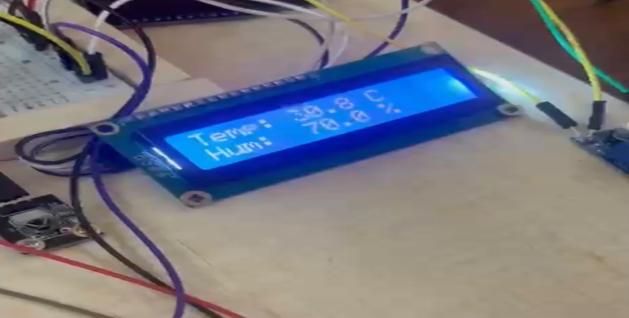
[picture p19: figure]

# 7. Personal Reflection

Working on this project improved my understanding of embedded control systems and sensor-based automation.

The main technical challenges were:

- Understanding sensor communication protocols.
- Integrating hardware and software together.
- Managing actuator power requirements.

This project provided practical experience in Arduino programming, electrical connections, relay control, and real-world automation applications.

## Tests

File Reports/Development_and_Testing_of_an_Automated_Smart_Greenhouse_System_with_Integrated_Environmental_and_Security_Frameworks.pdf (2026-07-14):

Lebanese university
Faculty of Engineering
Branch III

الجامعة اللبنانية
كليّة الهندسة
الث

الفرع الثّ

# Smart greenhouse

Presented to: Dr. Mohamad Aoude.

## Presented by :

Fatima jaafar (6591)
Mohamad injibar (6915)
Mostafa alawiyeh (6884)
Razan najem (6694)

The software of the smart greenhouse system was developed using Arduino C/C++ and implemented on the Arduino Mega 2560 platform. The program is designed to manage sensor data acquisition, automatic environmental control, user interaction,

## 1. Introduction

Agriculture is facing increasing challenges due to limited resources, climate changes, and the need for higher productivity. Traditional farming methods require continuous human monitoring and may lead to inefficient use of water, energy, and other resources.
A smart greenhouse provides an intelligent solution by using sensors and automation technologies to monitor and control environmental conditions. This project presents an Arduino-based smart greenhouse system that integrates different sensors to measure important parameters such as light intensity, temperature, humidity, water flow, and plant-related conditions.
The collected data are processed to evaluate greenhouse conditions, detect abnormal situations, and trigger automatic responses when needed. The objective of this project is to apply sensors and instrumentation concepts to develop a reliable monitoring system that improves plant growth conditions and optimizes resource usage.

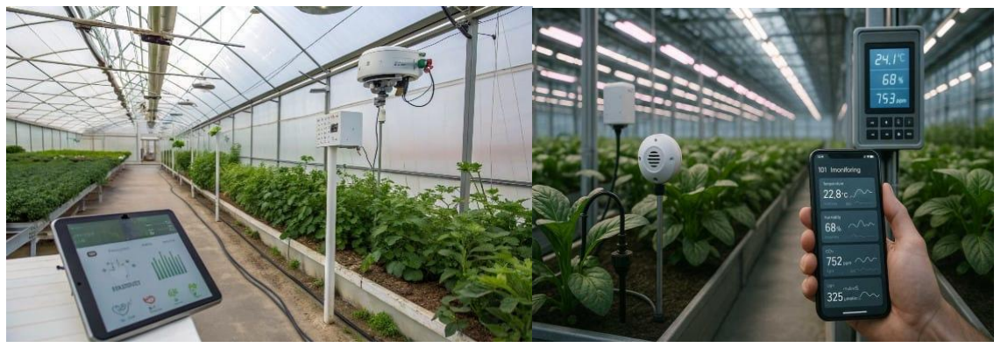
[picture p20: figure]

## 2. Problem Statement

Maintaining suitable environmental conditions is one of the main challenges in greenhouse agriculture. Traditional greenhouse systems usually require continuous human observation to monitor parameters such as temperature, humidity, soil moisture, water availability, and lighting conditions. This manual monitoring approach can lead to delayed responses, inefficient resource consumption, and unfavorable conditions that may affect plant growth.
The main problem addressed in this project is the need for an intelligent monitoring and control system capable of continuously measuring greenhouse conditions and automatically reacting to environmental changes. Variations in temperature, humidity, soil moisture, water level, and light intensity can negatively influence plant health if they are not detected and corrected in time.
To solve this problem, an Arduino Mega-based smart greenhouse system is proposed. The system integrates multiple sensors to collect real-time environmental data and uses this information to control different actuators, including a ventilation fan, irrigation pump, and servo mechanism. Warning indicators such as LEDs and a buzzer are also included to notify users when abnormal conditions are detected.
The proposed system aims to reduce human intervention, optimize water and energy consumption, and provide a reliable platform for monitoring and automatically controlling greenhouse conditions.

## 3. System Architecture

3.1 Overall System Architecture
The proposed smart greenhouse system is based on an Arduino Mega microcontroller that acts as the main processing and control unit. The Arduino Mega collects data from multiple sensors, processes the measurements according to predefined thresholds, and generates appropriate control signals for actuators and user notification devices. The system consists of four main layers:
1. Sensing Layer
2. Processing and Decision Layer
3. Actuation Layer
4. Monitoring and Security Layer
1) Sensing Layer (Input Sensors)

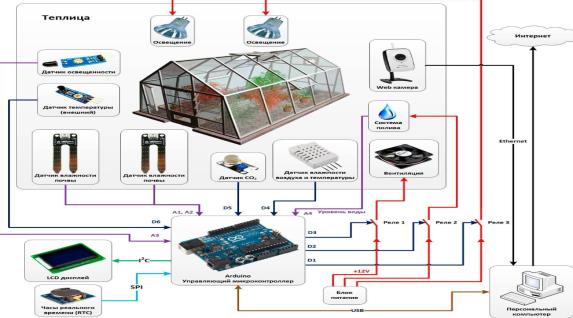
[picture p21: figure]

The Arduino Mega continuously receives environmental information from different sensors:

Sensor | Function | Arduino Input
DHT11 | Measures temperature and humidity | Digital pin 13
Soil Moisture Sensor | Measures soil water content | Analog pin A1
Water Level Sensor | Monitors water reservoir level | Analog pin A8
LDR Sensor | Measures light intensity | Analog pin A12
Raindrop Sensor | Detects rain intensity | Analog pin A10
Ultrasonic Sensor (HC-SR04) | Detects intrusion/object distance | Trig pin 4 / Echo pin 3
IR Receiver | Password/security control | Digital pin 2

2) Processing and Decision Layer
The Arduino Mega 2560 is the central controller of the system. Its main functions are:
- Reading all sensor values.
- Processing analog and digital signals.
- Comparing measurements with predefined thresholds.
- Taking automatic decisions.
- Controlling actuators.
- Sending information to the LCD display.
The implemented control logic includes:
- If temperature > 31°C → activate ventilation fan.
- If soil moisture < 35% → activate irrigation pump.
- If light intensity is high and no storm is detected → open roof using servo motor.
- If rain intensity is high → close roof.
- If unauthorized movement is detected → activate alarm system.
3) Actuation Layer (Outputs)
Based on sensor readings, the Arduino controls different actuators:
Actuator | Function | Control
DC Fan Motor (3–6V) | Greenhouse ventilation | Relay
Water Pump (5V) | Automatic irrigation | Relay
Servo Motor SG90 | Roof opening/closing mechanism | PWM signal
Red LED | Warning indicator | Digital output
Green LED | Normal operation indicator | Digital output
Buzzer | Alarm notification | Digital output
4) Monitoring and Security Layer
The system provides user interaction and protection through:
- I2C LCD 16×2 display

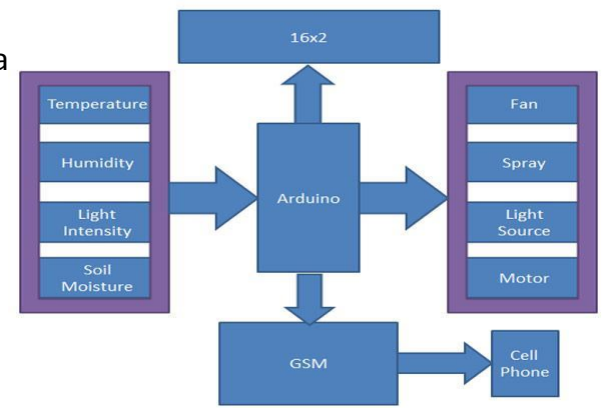
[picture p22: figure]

- Temperature and humidity display.
- Water level monitoring.
- Light and rain information.
- Soil moisture percentage.
- IR Remote Security System
- Allows password entry.
- Prevents unauthorized access.

- Ultrasonic Intrusion Detection
- Detects objects/persons near the greenhouse.
- Activates red LED and buzzer alarm when intrusion is detected.

## 4. Sensor Selection and Justification

The smart greenhouse system requires continuous monitoring of environmental parameters to maintain suitable conditions for plant growth and ensure safe operation. Several sensors were selected to collect real-time measurements, which are processed by the Arduino Mega controller to perform automatic decisions. Each sensor was chosen according to its measurement capability, compatibility with the Arduino platform, and its importance in greenhouse automation.

4.1 DHT11 Temperature and Humidity Sensor
Sensor Description
The DHT11 sensor was selected to measure the ambient temperature and relative humidity inside the greenhouse. These two parameters are essential because they directly influence plant growth, water evaporation, and overall greenhouse climate. The sensor provides digital output data, which allows direct
communication with the Arduino Mega without requiring
additional signal conditioning.
Justification and System Role

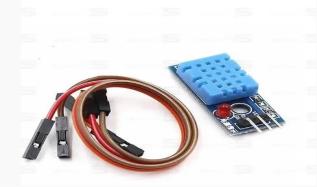
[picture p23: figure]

The DHT11 sensor serves as the primary environmental feedback trigger for thermodynamic regulation within the greenhouse. Temperature management is crucial for plants to regulate transpiration rates, stomatal opening, and photosynthetic efficiency; prolonged exposure to temperatures above optimal biological thresholds can lead to heat stress, enzyme denaturation, and wilting.

- System Role & Threshold Logic: When the ambient temperature surpasses
31 °C, the system initiates active ventilation by switching on the cooling fan relay. This active airflow expels trapped hot air and draws in cooler outside air. Once the internal temperature cools down to or below 31 °C, the fan is turned off to prevent unnecessary power consumption and over-cooling.
- Engineering Note on Demonstration Thresholds: While 31 °C is programmed as the activation setpoint, this specific value is chosen for rapid testing and demonstration purposes under indoor laboratory conditions. In a practical deployment, this boundary would be dynamic or set lower (e.g., 24 °C - 28°C) to match the specific botanical and seasonal requirements of the target crop, demonstrating the scalability of our control algorithms.

4.2 Soil Moisture Sensor
Sensor Description
The soil moisture sensor was selected to measure the amount of water present in the soil. This parameter is essential for determining irrigation
requirements and avoiding both plant dehydration and
excessive watering.
The sensor provides an analog signal proportional to the moisture level, which is converted by the Arduino Mega
ADC into a percentage value.
Justification and System Role

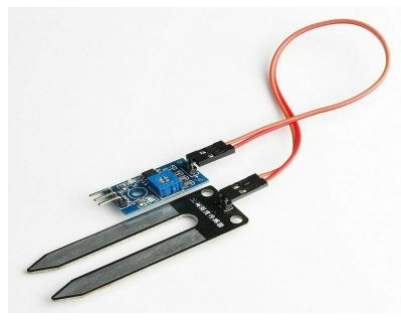
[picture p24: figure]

Justification and System Role: The soil moisture sensor provides closed-loop feedback to prevent both soil dehydration (which limits nutrient absorption and stunts plant growth) and soil waterlogging (which suffocates root structures and promotes fungal pathogens like root rot).

- System Role & Threshold Logic: To automate irrigation safely, the Arduino continuously polls soil moisture levels. When the mapped sensor percentage drops below 35%, it indicates that the root zone is reaching a critical drying state, prompting the Arduino to engage the 5V water pump relay. Crucially, the system continues to poll moisture levels during watering; once the sensor registers that the soil moisture has crossed the 35% threshold (plus a small software hysteresis gap), the pump automatically shuts off. This real-time loop prevents over-saturation and drastically reduces water waste.
- Engineering Note on Demonstration Thresholds: The 35% trigger threshold used in our demonstration program is selected specifically to allow for easy, visible state-transitions during lab testing (for instance, demonstrating a clear difference between an exposed sensor in air vs. a submerged sensor in a cup of soil). For real agricultural application, this threshold would be carefully calibrated based on the soil type (sandy, clayey, or loamy) and the specific permanent wilting point (PWP) of the cultivated crops.

4.3 LDR Light Sensor
Sensor Description
A Light Dependent Resistor (LDR) was selected to measure the intensity of light inside the greenhouse. The resistance of the LDR changes according to the amount of incident light, producing an analog voltage variation.
Photoresistor (LDR) Sensor:
In this project, a photoresistor was used to measure light
intensity. Since a photoresistor is commonly referred to
as an LDR (Light Dependent Resistor) and operates on the

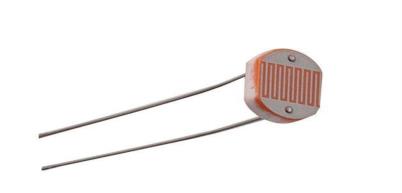
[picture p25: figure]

same principle, it is referred to as an LDR sensor throughout this report.
To convert the variable resistance of the LDR into a readable analog voltage, the sensor is configured as part of a static voltage divider circuit. Instead of an adjustable potentiometer, which can introduce mechanical instability, calibration drift, and contact resistance oxidation in a high-humidity greenhouse, a fixed, high-precision 10Kohms pull-down resistor was utilized. This design establishes a highly stable passive transducer circuit that outputs a reliable analog voltage proportional to the ambient light intensity.

Justification and System Role
The LDR sensor quantifies ambient sunlight levels, permitting the greenhouse to transition between passive solar heating and crop protection modes.
- System Role & Threshold Logic: Photosynthesis requires adequate solar radiation, yet structural heat build-up can occur under direct intensity. The roof control algorithm opens the ventilation hatches via the servo motor when ambient light exceeds 80%—provided no concurrent rain is detected—allowing maximum natural sunlight and fresh air circulation to reach the plants. Conversely, during low-light scenarios (below 80%) or night time, the roof is automatically closed. This locks in the internal thermal energy accumulated during the day, maintaining a warmer microclimate during colder night cycles.
- Engineering Note on Demonstration Thresholds: The high threshold of 80% is programmed to guarantee distinct control transitions during indoor laboratory testing, where artificial flashlights or desk lamps are used to simulate daylight. In an actual field installation, the threshold would be adjusted to account for natural lux levels of standard daylight cycles (typically opening the roof at much lower light levels like 20%-30% to maximize daily solar capture).

4.4 Water Level Sensor
Sensor Description
The water level sensor was selected to monitor the amount of water available in the irrigation reservoir. Maintaining sufficient water availability is important to ensure continuous operation of the irrigation system. The sensor provides an analog signal corresponding to
the detected water level.
Justification and System Role

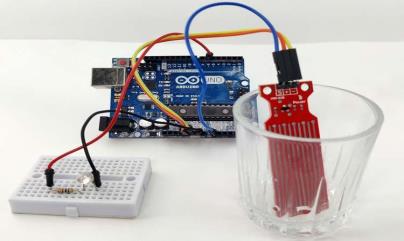
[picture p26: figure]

The water level sensor serves a dual role: providing real-time resource telemetry to the operator and establishing a critical safety interlock for the mechanical system.

- System Role & Safety Logic: Running a standard centrifugal DC water pump when the reservoir is entirely dry causes immediate motor overheating, frictional wear, and permanent damage. The Arduino continuously reads the analog output from the level sensor and categorizes the reservoir status into four states: DRY, LOW, MED, and HIGH. While this is presented to the user on the LCD screen for manual resource replenishment, the firmware utilizes this state matrix to temporarily disable the irrigation pump relay if a DRY state is detected, overriding any automatic watering commands from the soil moisture sensor.
- Engineering Note on Demonstration Thresholds: The level boundaries for the four states are calibrated based on the dimensions of our prototype testing reservoir (a shallow cup or small container). In a scaled agricultural reservoir or rain-harvesting tank, the sensor values would be mapped to volumetric measurements (e.g., liters remaining) using a deep-well pressure transducer or non-contact ultrasonic depth sensor, rather than the contact-based conductive strip used in our lab prototype.

4.5 Raindrop Sensor
Sensor Description
The raindrop sensor was selected to detect rain occurrence and protect the greenhouse from unfavorable weather conditions.
The sensor generates an analog signal depending on the amount of water detected on its surface.

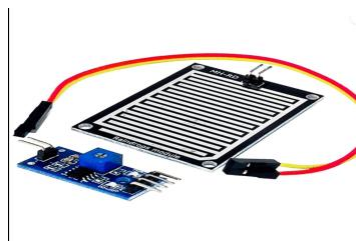
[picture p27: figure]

Justification and System Role
The raindrop sensor acts as a critical meteorological sensor, protecting the greenhouse’s internal environment from physical damage and water logging.
- System Role & Threshold Logic: Uncontrolled rainwater entering a precision greenhouse can cause soil erosion, over-saturation of nutrients, damage to sensitive electronics, and elevated internal relative humidity that encourages mold growth. The sensor continuously measures surface conductivity. When the mapped precipitation intensity exceeds the storm threshold of 70%, the Arduino immediately commands the SG90 roof servo to close the roof. This storm logic takes absolute priority over the LDR's light-based roof-opening commands, ensuring structural protection is maintained during sudden storms even if ambient light remains bright.
- Engineering Note on Demonstration Thresholds: The storm threshold (70%) is set high in our program to ensure that small droplets of moisture or condensation on the sensor surface do not trigger accidental roof closures during testing. For rapid lab demonstration, applying a few drops of water instantly breaches this threshold. In a permanent installation, a rain sensor heater circuit would be included to evaporate residual moisture, and the threshold would be calibrated to distinguish between a light mist and actual downpours.

4.6 Ultrasonic Sensor (HC-SR04)
Sensor Description
The ultrasonic sensor was selected as a security element to detect unauthorized movement near the greenhouse.
It operates by transmitting ultrasonic waves and measuring the time required for the echo signal to return. The distance is then calculated by
the Arduino.
Justification and System Role
The HC-SR04 ultrasonic sensor provides non-contact proximity detection, establishing a digital perimeter fence around the greenhouse structure.
- System Role & Security Logic: Agricultural assets and valuable crops inside greenhouses are susceptible to vandalism, theft, or animal intrusions. To safeguard the perimeter, the sensor emits high-frequency 40 kHz sonic pulses and calculates target distance based on the time-of-flight of the returning echo. If a physical object breaches the protective envelope (defined as a distance of less than 11cm), the Arduino triggers an immediate transition into Alarm Mode (Mode 3). This sounds the buzzer, flashes the red indicator, and locks the screen to request password verification. This automatic response acts as both an active deterrent and an operator alert system.
- Engineering Note on Demonstration Thresholds: A threshold of 11 cm was chosen specifically to match the physical dimensions of our tabletop prototype scale. This small distance allows a demonstrator to easily trigger the security system by placing their hand close to the prototype on a desk. In a commercial system, this ultrasonic sensor would be replaced by outdoor passive infrared (PIR) motion sensors or a long-range lidar/ultrasonic sensor array with a protective perimeter threshold mapped to several meters.

4.7 IR Receiver Module
Sensor Description
The IR receiver module was selected to provide wireless user interaction and security control.
It receives infrared signals transmitted by a remote control and
sends decoded commands to the Arduino Mega.
Justification and System Role
The IR receiver module functions as the localized human-machine interface (HMI) for access control and alarm management.
- System Role & Access Logic: A secure automated system must provide an authenticated bypass mechanism for authorized operators to perform maintenance or harvesting without triggering alarms. The IR module decodes incoming 38 kHz modulated infrared pulses from the remote. The system forces the operator to enter a multi-character passcode (#123). If verified, the microcontroller shifts the state machine out of Locked Mode (Mode 0) or Alarm Mode (Mode 3) and into Monitoring Mode (Mode 2), disengaging active alarms and restoring standard telemetry displays. If the passcode is entered incorrectly, access is denied, protecting the environmental configurations and physical actuators from unauthorized modification.
- Engineering Note on Demonstration Thresholds: The default passcode (#123) is hardcoded for simplicity and quick execution during academic evaluations

and grading. In an industry-standard deployment, a more secure cryptographic key or a rolling-code protocol would be implemented, and the passcode would be stored in the non-volatile EEPROM of the microcontroller, allowing the greenhouse administrator to update the password dynamically via a secure keypad or network interface.
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

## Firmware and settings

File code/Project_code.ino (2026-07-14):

// 1. Include the Libraries
#include <IRremote.hpp>
#include <IskakINO_LiquidCrystal_I2C.h>
#include <DHT.h>

// 2. Define all the Pins
int IR_PIN = 2;    
int ECHO_PIN = 3;  
int TRIG_PIN = 4;
int WATER_PIN = A8; 
int LIGHT_PIN = A12;  // Photoresistor Pin
int RAIN_PIN = A10;   // Raindrop Sensor Pin
int SOIL_PIN = A1;    // NEW: Soil Moisture Sensor Pin
int GREEN_LED = 10;
int RED_LED = 11;
int BUZZER = 12;      // AC Passive Buzzer Pin
int DHT_PIN = 13;
int FAN_RELAY = 53;   // Fan Relay Signal Pin

// 3. Setup the LCD and DHT sensors
LiquidCrystal_I2C lcd(16, 2); 
DHT dht(DHT_PIN, DHT11);

// 4. Variables for our Passcode System
String correctPassword = "#123";
String enteredPassword = "";

// 5. System Modes
// Mode 0 = Locked & Armed, Mode 1 = Gate Open (10s), Mode 2 = Post-Open Armed, Mode 3 = Alarm!
int systemMode = 0; 

// 6. Timers
unsigned long timerStart = 0;
unsigned long screenTimer = 0;
unsigned long blinkTimer = 0;
unsigned long fanTimer = 0; 
unsigned long serialTimer = 0; 
unsigned long alarmScreenTimer = 0; 

// Timers to manually oscillate the AC buzzer without crashing the IR Remote timer
unsigned long buzzerMicros = 0;
bool buzzerPinState = false;
bool shouldSound = false; 

// Screen Rotation State: 0 = Climate, 1 = Water Level, 2 = Light & Rain, 3 = Soil Moisture
int screenPage = 0; 
bool alarmToggleState = false; 

// 7. Threshold Settings & Noise Filtering
int intruderDistance = 5; 
int consecutiveTriggers = 0; 

void setup() {
  Serial.begin(9600);
  
  pinMode(TRIG_PIN, OUTPUT);
  pinMode(ECHO_PIN, INPUT);
  pinMode(GREEN_LED, OUTPUT);
  pinMode(RED_LED, OUTPUT);
  pinMode(BUZZER, OUTPUT);
  pinMode(WATER_PIN, INPUT); 
  pinMode(LIGHT_PIN, INPUT); 
  pinMode(RAIN_PIN, INPUT);
  pinMode(SOIL_PIN, INPUT); // NEW: Set soil pin as Input
  pinMode(FAN_RELAY, OUTPUT); 
  
  IrReceiver.begin(IR_PIN);
  dht.begin();
  
  lcd.begin();         
  lcd.backlight();
  
  // BOOT WARM-UP & CALIBRATION PERIOD
  lcd.clear();
  lcd.setCursor(0, 0);
  lcd.print("System Booting...");
  
  for (int i = 3; i > 0; i--) {
    lcd.setCursor(0, 1);
    lcd.print("Arming in: "); lcd.print(i); lcd.print("s ");
    getDistance(); 
    delay(1000);
  }
  
  lockGreenhouse();
}

void loop() {
  checkRemote();
  unsigned long currentTime = millis();

  // ------------------------------------------------------------------
  // Global Serial Monitor Telemetry (Runs every 2 seconds)
  // ------------------------------------------------------------------
  if (currentTime - serialTimer >= 2000) {
    serialTimer = currentTime;
    
    float currentTemp = getTemperature();
    float currentHum = getHumidity();
    int waterLevel = getWaterLevel();
    int lightPercentage = getLightLevel();
    int rainPercentage = getRainLevel();
    int soilPercentage = getSoilMoisture(); // NEW: Fetch soil telemetry
    
    Serial.println("--- GREENHOUSE SYSTEM STATUS ---");
    Serial.print("Active Mode: "); Serial.println(systemMode);
    
    if (!isnan(currentTemp) && !isnan(currentHum)) {
      Serial.print("Temperature: "); Serial.print(currentTemp, 1); Serial.println(" C");
      Serial.print("Humidity   : "); Serial.print(currentHum, 1); Serial.println(" %");
    } else {
      Serial.println("Temperature/Humidity: Error reading DHT sensor!");
    }
    
    Serial.print("Water Level: "); Serial.print(waterLevel);
    if (waterLevel == 0)      Serial.println(" (DRY)");
    else if (waterLevel == 1) Serial.println(" (LOW)");
    else if (waterLevel == 2) Serial.println(" (MED)");
    else if (waterLevel == 3) Serial.println(" (HIGH)");
    
    Serial.print("Light Level: "); Serial.print(lightPercentage); Serial.println(" %");
    Serial.print("Rain Fall  : "); Serial.print(rainPercentage); Serial.println(" %");
    Serial.print("Soil Moist : "); Serial.print(soilPercentage); Serial.println(" %"); // NEW: Print to Serial
    Serial.println("--------------------------------\n");
  }

  // ------------------------------------------------------------------
  // Automatic Fan Temperature Control (Checks every 2 seconds)
  // ------------------------------------------------------------------
  if (currentTime - fanTimer >= 2000) {
    fanTimer = currentTime;
    float currentTemp = getTemperature();
    
    if (!isnan(currentTemp)) {
      if (currentTemp > 30) {
        digitalWrite(FAN_RELAY, LOW);   
      } else {
        digitalWrite(FAN_RELAY, HIGH);  
      }
    }
  }

  // Security System Logic
  if (systemMode == 0) {
    float distance = getDistance();
    if (distance > 0.5 && distance < intruderDistance) { 
      consecutiveTriggers++;
      if (consecutiveTriggers >= 3) {
        triggerAlarm();
      }
    } else {
      consecutiveTriggers = 0; 
    }
  } 
  else if (systemMode == 1) { 
    digitalWrite(GREEN_LED, HIGH);
    updateScreen(currentTime);

    if (currentTime - timerStart >= 10000) {
      systemMode = 2; 
      digitalWrite(GREEN_LED, LOW); 
    }
  } 
  else if (systemMode == 2) { 
    updateScreen(currentTime); 

    float distance = getDistance();
    if (distance > 0.5 && distance < intruderDistance) { 
      consecutiveTriggers++;
      if (consecutiveTriggers >= 3) {
        triggerAlarm();
      }
    } else {
      consecutiveTriggers = 0;
    }
  } 
  else if (systemMode == 3) { 
    if (currentTime - blinkTimer >= 250) {
      blinkTimer = currentTime; 
      alarmToggleState = !alarmToggleState; 
      
      digitalWrite(RED_LED, alarmToggleState);
      shouldSound = alarmToggleState; 
    }

    if (currentTime - alarmScreenTimer >= 300) {
      alarmScreenTimer = currentTime;
      float distance = getDistance();
      
      lcd.setCursor(0, 0);
      lcd.print("Dist: ");
      if(distance == 999) {
        lcd.print("Out of Range   ");
      } else {
        lcd.print(distance, 1);
        lcd.print(" cm    "); 
      }
    }

    if (shouldSound == true) {
      unsigned long currentMicros = micros();
      if (currentMicros - buzzerMicros >= 500) { 
        buzzerMicros = currentMicros;
        buzzerPinState = !buzzerPinState;
        digitalWrite(BUZZER, buzzerPinState);
      }
    } else {
      digitalWrite(BUZZER, LOW); 
    }
  }
}

// ==========================================
//          CORE SYSTEM FUNCTIONS
// ==========================================

void checkRemote() {
  if (IrReceiver.decode()) {
    unsigned long code = IrReceiver.decodedIRData.decodedRawData;

    if (systemMode == 0 || systemMode == 3) {
      switch (code) {
        case 0xE916FF00: addNumber('1'); break;
        case 0xE619FF00: addNumber('2'); break;
        case 0xF20DFF00: addNumber('3'); break;
        case 0xF30CFF00: addNumber('4'); break;
        case 0xE718FF00: addNumber('5'); break;
        case 0xA15EFF00: addNumber('6'); break;
        case 0xF708FF00: addNumber('7'); break;
        case 0xE31CFF00: addNumber('8'); break;
        case 0xA55AFF00: addNumber('9'); break;
        case 0xAD52FF00: addNumber('0'); break;
        case 0xB54AFF00: addNumber('#'); break;
        
        case 0xBD42FF00: 
          enteredPassword = "";
          lcd.setCursor(6, 1);
          lcd.print("          "); 
          break;
          
        case 0xBF40FF00: 
          verifyPassword();
          break;
      }
    }
    IrReceiver.resume(); 
  }
}

void addNumber(char num) {
  enteredPassword += num;
  lcd.setCursor(6, 1); 
  lcd.print(enteredPassword);
}

void verifyPassword() {
  if (enteredPassword == correctPassword) {
    enteredPassword = "";
    shouldSound = false; 
    consecutiveTriggers = 0;
    
    digitalWrite(RED_LED, LOW);
    digitalWrite(BUZZER, LOW); 
    
    lcd.clear();
    lcd.setCursor(0, 0); 
    lcd.print("Code Matched!");
    lcd.setCursor(0, 1); 
    lcd.print("Opening Gate...");
    delay(1500); 
    lcd.clear();
    
    timerStart = millis(); 
    systemMode = 1; 
  } else {
    lcd.clear();
    lcd.setCursor(0,0);
    lcd.print("Access Denied!");
    delay(1000);
    
    enteredPassword = "";
    lcd.clear();
    if (systemMode == 3) {
      lcd.setCursor(0, 1);
      lcd.print("Code: ");
    } else {
      lockGreenhouse();
    }
  }
}

void lockGreenhouse() {
  systemMode = 0;
  enteredPassword = "";
  shouldSound = false;
  consecutiveTriggers = 0;
  digitalWrite(GREEN_LED, LOW);
  digitalWrite(RED_LED, LOW);
  digitalWrite(BUZZER, LOW);
  digitalWrite(FAN_RELAY, LOW); 
  lcd.clear();
  lcd.setCursor(0, 0); 
  lcd.print("Gate Code:"); 
}

void triggerAlarm() {
  systemMode = 3; 
  enteredPassword = ""; 
  lcd.clear();
  lcd.setCursor(0, 1);
  lcd.print("Code: "); 
}

void updateScreen(unsigned long currentTime) {
  // Page Swapper Strategy: Cycles through 4 screen pages every 5 seconds
  if (currentTime - screenTimer >= 5000) {
    screenTimer = currentTime;
    screenPage++;
    if(screenPage > 3) screenPage = 0; // MODIFIED: Wraps at page 3 instead of page 2
    lcd.clear();
  }

  if (screenPage == 0) {
    float temp = getTemperature();
    float hum = getHumidity();
    
    lcd.setCursor(0, 0);
    lcd.print("Temp: ");
    lcd.print(temp, 1);
    lcd.print(" C   ");
    
    lcd.setCursor(0, 1);
    lcd.print("Hum:  ");
    lcd.print(hum, 1);
    lcd.print(" %   ");
  } 
  else if (screenPage == 1) {
    int waterLevel = getWaterLevel();
    
    lcd.setCursor(0, 0);
    lcd.print("Water Reservoir");
    lcd.setCursor(0, 1);
    lcd.print("Level: ");
    
    if (waterLevel == 0)      lcd.print("DRY   ");
    else if (waterLevel == 1) lcd.print("LOW   ");
    else if (waterLevel == 2) lcd.print("MED   ");
    else if (waterLevel == 3) lcd.print("HIGH  ");
  } 
  else if (screenPage == 2) {
    int lightPercentage = getLightLevel();
    int rainPercentage = getRainLevel();
    
    lcd.setCursor(0, 0);
    lcd.print("Light: ");
    lcd.print(lightPercentage);
    lcd.print("%    ");
    
    lcd.setCursor(0, 1);
    lcd.print("Rain:  ");
    lcd.print(rainPercentage);
    lcd.print("%    ");
  }
  else if (screenPage == 3) {
    // ---- NEW PAGE 3: SOIL MOISTURE TELEMETRY ----
    int soilPercentage = getSoilMoisture();
    
    lcd.setCursor(0, 0);
    lcd.print("Soil Moisture");
    lcd.setCursor(0, 1);
    lcd.print("Level: ");
    lcd.print(soilPercentage);
    lcd.print("%    ");
  }
}

// ==========================================
//          HARDWARE SENSOR FUNCTIONS
// ==========================================

float getTemperature() { return dht.readTemperature(); }
float getHumidity() { return dht.readHumidity(); }

int getWaterLevel() {
  int rawValue = analogRead(WATER_PIN); 
  if (rawValue < 50)   return 0; 
  if (rawValue < 300)  return 1; 
  if (rawValue < 600)  return 2; 
  return 3; 
}

int getLightLevel() {
  int rawLight = analogRead(LIGHT_PIN);
  return map(rawLight, 0, 1023, 0, 100);
}

int getRainLevel() {
  int rawRain = analogRead(RAIN_PIN);
  int percentage = map(rawRain, 1023, 0, 0, 100);
  if(percentage < 0) percentage = 0;
  return percentage;
}

// NEW: Soil Moisture Logic Block
int getSoilMoisture() {
  int rawSoil = analogRead(SOIL_PIN);
  
  // CALIBRATION NOTE: 
  // 1023 represents total dryness in the air. 
  // 250 is an approximation of your sensor fully dipped in a cup of water.
  int percentage = map(rawSoil, 1023, 250, 0, 100);
  
  return constrain(percentage, 0, 100); 
}

float getDistance() {
  digitalWrite(TRIG_PIN, LOW);
  delayMicroseconds(2);
  digitalWrite(TRIG_PIN, HIGH);
  delayMicroseconds(10);
  digitalWrite(TRIG_PIN, LOW);
  
  long duration = pulseIn(ECHO_PIN, HIGH, 30000); 
  if (duration == 0) return 999; 
  
  return duration * 0.034 / 2;  
}
